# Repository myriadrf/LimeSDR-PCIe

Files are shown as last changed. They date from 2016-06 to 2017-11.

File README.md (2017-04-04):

# LimeSDR-PCIe

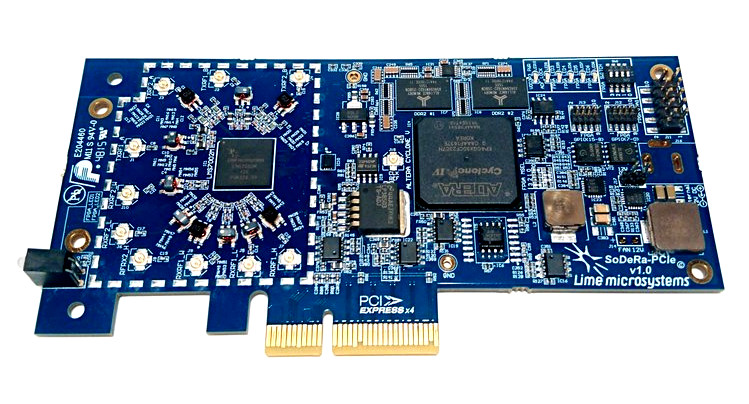
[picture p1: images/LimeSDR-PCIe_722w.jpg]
LimeSDR PCIe board


The [LimeSDR](https://myriadrf.org/projects/limesdr/) board provides a hardware platform for developing and prototyping high-performance and logic-intensive digital and RF designs using Altera’s Cyclone IV FPGA and Lime Microsystems transceiver.

## Contents

The directory structure is as follows:
         
      gateware/                  - Altera Cyclone IV FPGA project

      hardware/<version>/
          DFM/             	- Desgn for Manufacture related files
          EDA/              - Altium project files
          Info/            	- Files like schematic, BOM, 3D models etc. for end user

## Licensing

### Hardware

The hardware designs are licensed under a Creative Commons Attribution 3.0 Unported licence.

### FPGA design

For details of the FPGA design licensing please see the associated COPYING file(s). However, please note that this does not extend to any files provided with the Altera design tools or other third party IP, and see the relevant files for the associated terms and conditions.

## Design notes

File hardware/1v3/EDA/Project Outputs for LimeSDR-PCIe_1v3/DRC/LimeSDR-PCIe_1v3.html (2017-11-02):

Altium

# Design Rule Verification Report

Date: | | 2017-03-17
Time: | | 19:25:50
Elapsed Time: | | 00:03:00
Filename: | | E:\Saniok\Lime Micro\Lime PCBs\LimeSDR-PCIe_1v3\Altium Designer design files\PCB\LimeSDR-PCIe_1v3.PcbDoc

Warnings: | | 0
Rule Violations: | | 0

## Summary

Warnings | Count
Total | 0

Rule Violations | Count
Component Clearance Constraint ( Horizontal Gap = -1mm, Vertical Gap = 0.254mm ) (InComponent('R107') or InComponent('R113') or InComponent('R114') or InComponent('R115') or InComponent('R116') or InComponent('R117') or InComponent('R118')),(InComponent('R107') or InComponent('R113') or InComponent('R114') or InComponent('R115') or InComponent('R116') or InComponent('R117') or InComponent('R118')) | 0
Short-Circuit Constraint (Allowed=Yes) (InComponent('IC8') and IsComponentPad and ((Name='IC8-H14') or (Name='IC8-C10') or (Name='IC8-A11') or (Name='IC8-A12') )),(All) | 0
Width Constraint (Min=0.1mm) (Max=10mm) (Preferred=0.2mm) (All) | 0
Component Clearance Constraint ( Horizontal Gap = -1mm, Vertical Gap = Infinite ) (InComponent('IC9')),(InComponent('IC10')) | 0
Differential Pairs Uncoupled Length using the Gap Constraints (Min=0.1mm) (Max=0.3mm) (Prefered=0.2mm) and Width Constraints (Min=0.1mm) (Max=0.3mm) (Prefered=0.2mm) (InNetClass('RX_RF')) | 0
Differential Pairs Uncoupled Length using the Gap Constraints (Min=0.1mm) (Max=0.3mm) (Prefered=0.2mm) and Width Constraints (Min=0.1mm) (Max=0.3mm) (Prefered=0.2mm) (InNetClass('TX_RF')) | 0
Differential Pairs Uncoupled Length using the Gap Constraints (Min=0.1mm) (Max=0.3mm) (Prefered=0.1mm) and Width Constraints (Min=0.2mm) (Max=0.2mm) (Prefered=0.2mm) (InNetClass('FX3_DATA')) | 0
Matched Lengths(Tolerance=0.5mm) (InNetClass('LMS_PORT2')) | 0
Matched Lengths(Tolerance=0.5mm) (InNetClass('LMS_PORT1')) | 0
Differential Pairs Uncoupled Length using the Gap Constraints (Min=0.1mm) (Max=0.2mm) (Prefered=0.1mm) and Width Constraints (Min=0.1mm) (Max=0.4mm) (Prefered=0.1mm) (InNetClass('DDR2_1_CK') or InNetClass('DDR2_1_CK')) | 0
Modified Polygon (Allow modified: No), (Allow shelved: No) | 0
Height Constraint (Min=0mm) (Max=2.67mm) (Prefered=2.67mm) (OnBottomLayer) | 0
Component Clearance Constraint ( Horizontal Gap = 0.01mm, Vertical Gap = 0.254mm ) (All),(All) | 0
Differential Pairs Uncoupled Length using the Gap Constraints (Min=0.1mm) (Max=0.3mm) (Prefered=0.1mm) and Width Constraints (Min=0.1mm) (Max=0.5mm) (Prefered=0.2mm) (All) | 0
Height Constraint (Min=0mm) (Max=14.47mm) (Prefered=14.47mm) (OnTopLayer) | 0
Hole Size Constraint (Min=0.2mm) (Max=10mm) (All) | 0
Pads and Vias to follow the Drill pairs settings | 0
Routing Via (MinHoleWidth=0.2mm) (MaxHoleWidth=4.5mm) (PreferredHoleWidth=0.2mm) (MinWidth=0.31mm) (MaxWidth=5mm) (PreferedWidth=0.4mm) (All) | 0
Width Constraint (Min=0.1mm) (Max=5mm) (Preferred=0.2mm) (All) | 0
Power Plane Connect Rule(Relief Connect )(Expansion=0.508mm) (Conductor Width=0.254mm) (Air Gap=0.254mm) (Entries=4) (All) | 0
Un-Routed Net Constraint ( (All) ) | 0
Short-Circuit Constraint (Allowed=No) (All),(All) | 0
Clearance Constraint (Gap=0.1mm) (All),(All) | 0
Routing Layers(All) | 0
Hole To Hole Clearance (Gap=0.15mm) (All),(All) | 0
Net Antennae (Tolerance=0mm) (All) | 0
Matched Lengths(Tolerance=0.5mm) (InNetClass('DDR2_2_DQ[0..15]')) | 0
Matched Lengths(Tolerance=0.5mm) (InNetClass('DDR2_2_A[0..12]')) | 0
Matched Lengths(Tolerance=0.5mm) (InNetClass('DDR2_1_DQ[0..15]')) | 0
Matched Lengths(Tolerance=0.5mm) (InNetClass('DDR2_1_A[0..12]')) | 0
Differential Pairs Uncoupled Length using the Gap Constraints (Min=0.1mm) (Max=0.2mm) (Prefered=0.1mm) and Width Constraints (Min=0.1mm) (Max=0.4mm) (Prefered=0.1mm) (InNet('FX3_XTAL_N') or InNet('FX3_XTAL_P')) | 0
Total | 0

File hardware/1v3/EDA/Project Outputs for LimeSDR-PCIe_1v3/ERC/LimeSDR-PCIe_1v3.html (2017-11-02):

Altium

# Electrical Rule Check Report

Date: | | 2017-03-17
Time: | | 19:28:52
Filename: | | E:\Saniok\Lime Micro\Lime PCBs\LimeSDR-PCIe_1v3\Altium Designer design files\Project Outputs for LimeSDR-PCIe_1v3\ERC\LimeSDR-PCIe_1v3.html

Class | Document | Message
Warning | 13_Periphs.SchDoc | FPGA_LED1_R contains IO Pin and Power Pin objects (Pin LED1-3,Pin IC8-E20,Pin LEDS1-K1)
Warning | 13_Periphs.SchDoc | FPGA_LED2_R contains IO Pin and Power Pin objects (Pin LED4-3,Pin IC8-G21,Pin LEDS1-K2)

Warning

16_BoardPowerSupply.SchDoc

GND contains IO Pin and Power Pin objects (Pin J11-2,Pin IC17-5,Pin J11-10,Pin IC12-A3,Pin IC11-A3,Pin IC12-A7,Pin IC11-A7,Pin IC8-A11,Pin IC8-A12,Pin IC12-B2,Pin IC11-B2,Pin IC12-B8,Pin IC11-B8,Pin IC8-B18,Pin IC12-D2,Pin IC11-D2,Pin IC8-D2,Pin IC12-D8,Pin IC11-D8,Pin IC8-D10,Pin IC8-D11,Pin IC8-D12,Pin IC8-D13,Pin IC8-D16,Pin IC12-E3,Pin IC11-E3,Pin IC12-E7,Pin IC11-E7,Pin IC12-F2,Pin IC11-F2,Pin IC12-F8,Pin IC11-F8,Pin IC8-F12,Pin IC8-G18,Pin IC12-H2,Pin IC11-H2,Pin IC12-H8,Pin IC11-H8,Pin IC8-H17,Pin IC12-J3,Pin IC11-J3,Pin IC12-J7,Pin IC11-J7,Pin IC8-J15,Pin LED9-K,Pin LED8-K,Pin LED7-K,Pin LED6-K,Pin LED5-K,Pin IC12-N1,Pin IC11-N1,Pin IC12-P9,Pin IC11-P9)
Warning | 05_LMS7002M_RF1.SchDoc | Net NetC10_1 has no driving source (Pin C10-1,Pin IC4-5)
Warning | 05_LMS7002M_RF1.SchDoc | Net NetC18_1 has no driving source (Pin C18-1,Pin IC5-5)
Warning | 06_LMS7002M_RF2.SchDoc | Net NetC29_1 has no driving source (Pin C29-1,Pin IC6-5)
Warning | 06_LMS7002M_RF2.SchDoc | Net NetC37_1 has no driving source (Pin C37-1,Pin IC7-5)
Warning | 14_Clocks_1.SchDoc | Net NetC325_2 has no driving source (Pin C325-2,Pin XO3-7)
Warning | 16_BoardPowerSupply.SchDoc | Net NetC381_2 has no driving source (Pin C381-2,Pin FR51-2,Pin IC24-5,Pin IC24-8)
Warning | 16_BoardPowerSupply.SchDoc | Net NetC389_2 has no driving source (Pin C389-2,Pin FR52-2,Pin IC26-5,Pin IC26-8)
Warning | 16_BoardPowerSupply.SchDoc | Net NetC403_2 has no driving source (Pin C403-2,Pin FR53-2,Pin IC29-5,Pin IC29-8)
Warning | 16_BoardPowerSupply.SchDoc | Net NetC420_2 has no driving source (Pin C420-2,Pin FR55-2,Pin IC32-3)
Warning | 16_BoardPowerSupply.SchDoc | Net NetC421_2 has no driving source (Pin C421-2,Pin IC32-1,Pin R178-2,Pin R179-1)
Warning | 16_BoardPowerSupply.SchDoc | Net NetIC32_8 has no driving source (Pin IC32-8,Pin R176-2,Pin R177-2)
Warning | 14_Clocks_1.SchDoc | Net NetR118_2 has no driving source (Pin R118-2,Pin XO3-1)
Warning | 11_FPGA_power.SchDoc | VCC2P5A_FPGA contains IO Pin and Power Pin objects (Pin J11-4,Pin IC8-F4,Pin IC8-F19,Pin IC8-L4,Pin IC8-P7,Pin IC8-T5,Pin IC8-U19,Pin IC8-V4)
Warning | 16_BoardPowerSupply.SchDoc | VCC3P3 contains IO Pin and Power Pin objects (Pin IC10-2,Pin IC8-E13,Pin IC8-E14,Pin IC8-E15,Pin IC8-E16,Pin IC8-F14,Pin IC8-G4,Pin IC8-H19,Pin IC8-J18,Pin IC8-K18)

Back to top

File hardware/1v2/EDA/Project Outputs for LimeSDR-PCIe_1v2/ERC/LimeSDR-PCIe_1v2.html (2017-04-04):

Altium

# Electrical Rule Check Report

Date: | | 2016-09-22
Time: | | 11:58:19
Filename: | | E:\Saniok\Lime Micro\Lime PCBs\LimeSDR-PCIe_1v2\Altium Designer Design Files\Project Outputs for LimeSDR-PCIe_1v1\ERC\LimeSDR-PCIe_1v2.html

Class | Document | Message
Warning | 13_Periphs.SchDoc | FPGA_LED1_R contains IO Pin and Power Pin objects (Pin LED1-3,Pin IC8-E20,Pin LEDS1-K1)
Warning | 13_Periphs.SchDoc | FPGA_LED2_R contains IO Pin and Power Pin objects (Pin LED4-3,Pin IC8-G21,Pin LEDS1-K2)

Warning

16_BoardPowerSupply.SchDoc

GND contains IO Pin and Power Pin objects (Pin J11-2,Pin IC18-5,Pin J11-10,Pin IC12-A3,Pin IC11-A3,Pin IC12-A7,Pin IC11-A7,Pin IC8-A11,Pin IC8-A12,Pin IC12-B2,Pin IC11-B2,Pin IC12-B8,Pin IC11-B8,Pin IC8-B18,Pin IC12-D2,Pin IC11-D2,Pin IC8-D2,Pin IC12-D8,Pin IC11-D8,Pin IC8-D10,Pin IC8-D11,Pin IC8-D12,Pin IC8-D13,Pin IC8-D16,Pin IC12-E3,Pin IC11-E3,Pin IC12-E7,Pin IC11-E7,Pin IC12-F2,Pin IC11-F2,Pin IC12-F8,Pin IC11-F8,Pin IC8-F12,Pin IC8-G18,Pin IC12-H2,Pin IC11-H2,Pin IC12-H8,Pin IC11-H8,Pin IC8-H14,Pin IC8-H17,Pin IC12-J3,Pin IC11-J3,Pin IC12-J7,Pin IC11-J7,Pin IC8-J15,Pin LED9-K,Pin LED8-K,Pin LED7-K,Pin LED6-K,Pin LED5-K,Pin IC12-N1,Pin IC11-N1,Pin IC12-P9,Pin IC11-P9)
Warning | 05_LMS7002M_RF1.SchDoc | Net NetC10_1 has no driving source (Pin C10-1,Pin IC4-5)
Warning | 05_LMS7002M_RF1.SchDoc | Net NetC18_1 has no driving source (Pin C18-1,Pin IC5-5)
Warning | 06_LMS7002M_RF2.SchDoc | Net NetC29_1 has no driving source (Pin C29-1,Pin IC6-5)
Warning | 06_LMS7002M_RF2.SchDoc | Net NetC37_1 has no driving source (Pin C37-1,Pin IC7-5)
Warning | 16_BoardPowerSupply.SchDoc | Net NetC379_2 has no driving source (Pin C379-2,Pin FR51-2,Pin IC25-5,Pin IC25-8)
Warning | 16_BoardPowerSupply.SchDoc | Net NetC387_2 has no driving source (Pin C387-2,Pin FR52-2,Pin IC27-5,Pin IC27-8)
Warning | 16_BoardPowerSupply.SchDoc | Net NetC401_2 has no driving source (Pin C401-2,Pin FR53-2,Pin IC30-5,Pin IC30-8)
Warning | 16_BoardPowerSupply.SchDoc | Net NetC418_2 has no driving source (Pin C418-2,Pin FR55-2,Pin IC33-3)
Warning | 16_BoardPowerSupply.SchDoc | Net NetC419_2 has no driving source (Pin C419-2,Pin IC33-1,Pin R176-2,Pin R177-1)
Warning | 16_BoardPowerSupply.SchDoc | Net NetIC33_8 has no driving source (Pin IC33-8,Pin R174-2,Pin R175-2)
Warning | 11_FPGA_power.SchDoc | VCC2P5A_FPGA contains IO Pin and Power Pin objects (Pin J11-4,Pin IC8-F4,Pin IC8-F19,Pin IC8-L4,Pin IC8-N12,Pin IC8-T5,Pin IC8-U19,Pin IC8-V4)
Warning | 16_BoardPowerSupply.SchDoc | VCC3P3 contains IO Pin and Power Pin objects (Pin IC10-2,Pin IC8-E13,Pin IC8-E14,Pin IC8-E15,Pin IC8-E16,Pin IC8-F14,Pin IC8-G4,Pin IC8-H19,Pin IC8-J18,Pin IC8-K18)

Back to top

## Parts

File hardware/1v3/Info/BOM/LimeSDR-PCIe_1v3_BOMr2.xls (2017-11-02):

Item # | Comment | Quantity | Designator | Footprint | Manufacturer | Manufacturer Part Number 1 | Supplier 1 | Supplier Part Number 1 | Part Description | Assembly Info
1 | 10pF, 5% | 4 | C1, C352, C355, C356 | CAP0402 | AVX | 04023A100JAT2A | Farnell | 2332478RL | 10pF ±5% 25V C0G, NP0 Ceramic Capacitor -55°C ~ 125°C Surface Mount, MLCC 0402 (1005 Metric) 0.039" L x 0.020" W (1.00mm x 0.50mm)
2 | 1uF, 10V | 4 | C2, C3, C318, C323 | CAP0402 | TDK | GRM155R61A105KE15J | Newark | 490-6298-2-ND | 1µF ±10% 10V X5R Ceramic Capacitor -55°C ~ 85°C Surface Mount, MLCC 0402 (1005 Metric) 0.039" L x 0.020" W (1.00mm x 0.50mm)
3 | 100nF, 10% | 183 | C4, C5, C7, C8, C23, C24, C26, C27, C101, C102, C103, C104, C105, C106, C107, C108, C109, C110, C111, C112, C113, C114, C115, C116, C117, C118, C119, C126, C132, C138, C144, C150, C156, C162, C168, C169, C170, C171, C172, C173, C174, C175, C176, C177, C178, C179, C180, C181, C182, C183, C184, C185, C186, C187, C188, C189, C190, C191, C192, C193, C194, C195, C196, C197, C198, C199, C200, C201, C202, C203, C204, C205, C206, C207, C208, C209, C210, C211, C212, C213, C214, C215, C216, C217, C218, C219, C220, C221, C222, C223, C224, C225, C226, C227, C228, C229, C230, C231, C232, C233, C234, C235, C236, C237, C238, C239, C240, C241, C242, C243, C244, C245, C246, C247, C248, C249, C250, C251, C252, C253, C254, C256, C257, C258, C259, C260, C261, C262, C263, C265, C266, C267, C268, C273, C274, C276, C277, C278, C279, C281, C282, C283, C284, C286, C287, C288, C289, C290, C291, C292, C293, C298, C299, C300, C302, C303, C304, C305, C306, C312, C313, C314, C327, C335, C338, C339, C345, C353, C354, C357, C358, C359, C361, C363, C365, C367, C378, C397, C398, MN5, MN8, MN33, MN36 | CAP0402 | Murata Electronics | GRM155R71C104KA88D | Mouser | 81-GRM155R71C104KA88 | 0.10µF ±10% 16V X7R Ceramic Capacitor -55°C ~ 125°C Surface Mount, MLCC 0402 (1005 Metric) 0.039" L x 0.020" W (1.00mm x 0.50mm)
4 | 100nF, 16V | 6 | C6, C25, C317, C320, C324, C331 | CAP0402 | Murata Electronics | GRM155R71C104KA88D | Mouser | 81-GRM155R71C104KA88 | 0.10µF ±10% 16V X7R Ceramic Capacitor -55°C ~ 125°C Surface Mount, MLCC 0402 (1005 Metric) 0.039" L x 0.020" W (1.00mm x 0.50mm)
5 | 100pF, 50V | 20 | C9, C10, C13, C15, C16, C17, C18, C19, C28, C29, C32, C34, C35, C36, C37, C38, C321, C322, C332, C333 | CAP0402 | Yageo | CC0402JRNPO9BN101 | Digi-Key | 311-1024-1-ND | 100pF ±5% 50V C0G, NP0 Ceramic Capacitor -55°C ~ 125°C Surface Mount, MLCC 0402 (1005 Metric) 0.039" L x 0.020" W (1.00mm x 0.50mm)
6 | 47pF | 10 | C11, C12, C20, C21, C30, C31, C39, C40, C315, C316 | CAP0402 | TDK Corporation | C1005C0G1H470F050BA | Digi-Key | 445-5361-1-ND | 47pF ±1% 50V C0G, NP0 Ceramic Capacitor -55°C ~ 125°C Surface Mount, MLCC 0402 (1005 Metric) 0.039" L x 0.020" W (1.00mm x 0.50mm) | NF(C315 C316)
7 | 470pF, 50V | 4 | C14, C22, C33, C41 | CAP0402 | TDK Corporation | C1005C0G1H471J050BA | Digi-Key | 445-2656-6-ND | 470pF ±5% 50V C0G, NP0 Ceramic Capacitor -55°C ~ 125°C Surface Mount, MLCC 0402 (1005 Metric) 0.039" L x 0.020" W (1.00mm x 0.50mm)
8 | 1uF, 20% | 50 | C42, C44, C46, C48, C50, C52, C53, C54, C55, C56, C57, C58, C59, C60, C61, C62, C63, C64, C66, C68, C70, C72, C73, C74, C75, C76, C77, C78, C79, C80, C81, C82, C83, C84, C85, C86, C87, C88, C89, C90, C91, C92, C93, C94, C95, C96, C97, C98, C99, C100 | CAP0201 | TDK Corporation | C0603X5R0J105M030BC | Digi-Key | 445-8008-1-ND | 1µF ±20% 6.3V X5R Ceramic Capacitor -55°C ~ 85°C Surface Mount, MLCC 0201 (0603 Metric) 0.024" L x 0.012" W (0.60mm x 0.30mm)
9 | 1nF, 10% | 9 | C43, C45, C47, C49, C51, C65, C67, C69, C71 | CAP0201 | TDK Corporation | C0603X7R1E102K030BA | Digi-Key | 445-7275-1-ND | 1000pF ±10% 25V X7R Ceramic Capacitor -55°C ~ 125°C Surface Mount, MLCC 0201 (0603 Metric) 0.024" L x 0.012" W (0.60mm x 0.30mm)
10 | 220uF, 4V | 14 | C120, C121, C122, C127, C128, C133, C134, C139, C145, C151, C275, C405, C406, C407 | CAP1206 | Murata Electronics North America | GRM31CR60G227ME11L | Digi-Key | 490-9774-1-ND | 220µF ±20% 4V X5R Ceramic Capacitor -55°C ~ 85°C Surface Mount, MLCC 1206 (3216 Metric) 0.126" L x 0.063" W (3.20mm x 1.60mm) | NF(C407)
11 | 10uF, 6.3V | 13 | C123, C129, C135, C141, C147, C153, C159, C165, C270, C295, C386, C395, C396 | CAP0603 | Yageo | CC0603MRX5R5BB106 | Digi-Key | 311-1448-2-ND | 10µF ±20% 6.3V X5R Ceramic Capacitor -55°C ~ 85°C Surface Mount, MLCC 0603 (1608 Metric) 0.063" L x 0.031" W (1.60mm x 0.80mm)
12 | 4.7uF, 6.3V | 35 | C124, C130, C136, C142, C148, C154, C160, C166, C271, C296, C319, C326, C330, C334, C360, C362, C364, C366, C375, C376, C380, C381, C382, C388, C389, C390, C393, C400, C401, C402, C403, C404, C412, C415, C416 | CAP0402 | Murata Electronics North America | GRM155R60J475ME87D | Digi-Key | 490-5408-1-ND | 4.7µF ±20% 6.3V X5R Ceramic Capacitor -55°C ~ 85°C Surface Mount, MLCC 0402 (1005 Metric) 0.039" L x 0.020" W (1.00mm x 0.50mm) | NF(C334)
13 | 1uF, 10% | 12 | C125, C131, C137, C143, C149, C155, C161, C167, C272, C297, C387, C408 | CAP0402 | TDK | GRM155R61A105KE15J | Newark | 490-6298-2-ND | 1µF ±10% 10V X5R Ceramic Capacitor -55°C ~ 85°C Surface Mount, MLCC 0402 (1005 Metric) 0.039" L x 0.020" W (1.00mm x 0.50mm)
14 | 100uF, 6.3V | 10 | C140, C146, C152, C157, C158, C163, C164, C383, C384, C385 | CAP1206 | MURATA | GRM31CR60J107ME39L. | Farnell | 1735535 | SMD Multilayer Ceramic Capacitor, GRM Series, 100 µF, ± 20%, X5R, 6.3 V, 1206 [3216 Metric] | NF(C385)
15 | 0.1uF | 6 | C255, C264, C269, C280, C285, C294 | CKCA43X7R1C104M100AA | TDK | CKCA43X7R1C104M100AA | Mouser | 810-CKCA43X7R1C104M | CAP ARRAY 0.1UF 16V X7R 1206
16 | 22nF, 50V | 11 | C301, C307, C308, C309, C310, C311, C373, C374, C377, C394, C411 | CAP0402 | Kemet | C0402C223K5RACTU | Digi-Key | 399-7780-1-ND | 0.022µF ±10% 50V X7R Ceramic Capacitor -55°C ~ 125°C Surface Mount, MLCC 0402 (1005 Metric) 0.039" L x 0.020" W (1.00mm x 0.50mm)
17 | 18nF, 16V | 1 | C325 | CAP0402 | Yageo | CC0402KRX7R7BB183 | Digi-Key | 311-1706-1-ND | CAP CER 0.018UF 16V X7R 0402
18 | 100pF, 5% | 13 | C328, C329, C336, C337, C340, C341, C342, C343, C344, MN25, MN28, MN53, MN56 | CAP0402 | Yageo | CC0402JRNPO9BN101 | Digi-Key | 311-1024-1-ND | 100pF ±5% 50V C0G, NP0 Ceramic Capacitor -55°C ~ 125°C Surface Mount, MLCC 0402 (1005 Metric) 0.039" L x 0.020" W (1.00mm x 0.50mm)
19 | 1nF, 10% | 2 | C346, C347 | CAP0402 | Murata Electronics | GCM155R71H102KA37D | Mouser | 81-GCM155R71H102KA7D | 1000pF ±10% 50V X7R Ceramic Capacitor -55°C ~ 125°C Surface Mount, MLCC 0402 (1005 Metric) 0.039" L x 0.020" W (1.00mm x 0.50mm)
20 | 22pF, 5% | 3 | C348, C349, C350 | CAP0402 | Yageo | CC0402JRNPO9BN220 | Digi-Key | 311-1018-2-ND | 22pF ±5% 50V C0G, NP0 Ceramic Capacitor -55°C ~ 125°C Surface Mount, MLCC 0402 (1005 Metric) 0.039" L x 0.020" W (1.00mm x 0.50mm)
21 | 220pF, 10% | 1 | C351 | CAP0402 | Yageo | CC0402KRX7R9BB221 | Digi-Key | 311-1035-2-ND | 220pF ±10% 50V X7R Ceramic Capacitor -55°C ~ 125°C Surface Mount, MLCC 0402 (1005 Metric) 0.039" L x 0.020" W (1.00mm x 0.50mm)
22 | 10uF, 25V | 10 | C368, C369, C370, C371, C372, C379, C399, C419, C420, C421 | CAP0603 | Murata Electronics North America | GRM188R61E106MA73D | Digi-Key | 490-7202-2-ND | 10µF ±20% 25V X5R Ceramic Capacitor -55°C ~ 85°C Surface Mount, MLCC 0603 (1608 Metric) 0.063" L x 0.031" W (1.60mm x 0.80mm)
23 | 4.7pF | 1 | C391 | CAP0402 | MURATA | GRM1555C1H4R7CA01D | Farnell | 2434644 | 4.7pF ±0.25pF 50V C0G, NP0 Ceramic Capacitor -55°C ~ 125°C Surface Mount, MLCC 0402 (1005 Metric) 0.039" L x 0.020" W (1.00mm x 0.50mm)
24 | 1200pF | 1 | C392 | CAP0402 | Kemet | C0402C122J5GACTU | Digi-Key | 399-7334-1-ND | 1200pF ±5% 50V C0G, NP0 Ceramic Capacitor -55°C ~ 125°C Surface Mount, MLCC 0402 (1005 Metric) 0.039" L x 0.020" W (1.00mm x 0.50mm)
25 | 68pF | 1 | C409 | CAP0402 | Kemet | CBR04C680F3GAC | Digi-Key | 399-11255-1-ND | 68pF ±1% 25V C0G, NP0 Ceramic Capacitor -55°C ~ 125°C Surface Mount, MLCC 0402 (1005 Metric) 0.039" L x 0.020" W (1.00mm x 0.50mm)
26 | 1500pF | 1 | C410 | CAP0402 | Samsung Electro-Mechanics America, Inc. | CL05B152KB5NNNC | Digi-Key | 1276-1521-1-ND | 1500pF ±10% 50V X7R Ceramic Capacitor -55°C ~ 125°C Surface Mount, MLCC 0402 (1005 Metric) 0.039" L x 0.020" W (1.00mm x 0.50mm)
27 | 10uF, 20% | 4 | C413, C414, C417, C418 | CAP0603 | Yageo | GRM188R61C106MA73D | Digi-Key | 490-7201-2-ND | 10µF ±20% 16V X5R Ceramic Capacitor -55°C ~ 85°C Surface Mount, MLCC 0603 (1608 Metric) 0.063" L x 0.031" W (1.60mm x 0.80mm)
28 | Fiducial | 8 | F1, F2, F3, F4, F5, F6, F7, F8 | Fiducial | - | - | - | - | -
29 | Local 'Fiducial | 8 | FL1, FL2 | Fiducial_local | - | - | - | - | -
30 | 600R, 0.27A | 38 | FR1, FR2, FR3, FR4, FR5, FR6, FR7, FR8, FR9, FR10, FR11, FR12, FR13, FR14, FR15, FR16, FR17, FR18, FR19, FR20, FR21, FR22, FR23, FR24, FR25, FR26, FR27, FR28, FR29, FR30, FR31, FR32, FR33, FR34, FR35, FR47, FR48, FR49 | RES0201 | Taiyo Yuden | BK0603TS601-T | Digi-Key | 587-3277-1-ND | FERRITE BEAD 600 OHM 0201 1LN | NF(FR29 FR31)
31 | 600R, 2A | 18 | FR36, FR37, FR38, FR39, FR40, FR41, FR42, FR43, FR44, FR45, FR46, FR50, FR51, FR52, FR53, FR54, FR55, FR56 | RES0805 | TDK Corporation | MPZ2012S601AT000 | Digi-Key | 445-2206-2-ND | FERRITE BEAD 600 OHM 0805 1LN
32 | LMS7002M | 1 | IC1 | LMS7002M_v2 | Lime Microsystems | LMS7002M | Lime Microsystems | LMS7002M | IC FPRF Transceiver LMS7002M; 261 pin aQFN
33 | M24128 | 2 | IC2, IC15 | 24FC512 | STMicroelectronics | M24128-DRDW8TP/K | Digi-Key | 497-15336-1-ND | IC EEPROM 128KBIT 1MHZ 8TSSOP
34 | 24FC512 | 1 | IC3 | 24FC512 | Microchip Technology | 24FC512-I/ST | Digi-Key | 24FC512-I/ST-ND | IC EEPROM 512KBIT 1MHZ 8TSSOP
35 | SKY13323 | 4 | IC4, IC5, IC6, IC7 | SKY13323-378LF | Skyworks Solutions Inc. | SKY13323-378LF | Digi-Key | 683-1334-1-ND | IC SPDT 100MHZ-3GHZ 6-MLPD
36 | EP4CGX30CF23C7N | 1 | IC8 | ALTR-FBGA484_A-200 | Altera | EP4CGX30CF23C7N | Digi-Key | 544-2730-ND | IC FPGA 290 I/O 484FBGA
37 | S25FL164K | 1 | IC9 | S25FL164K_WSO8N | Cypress Semiconductor Corp | S25FL164K0XMFI011 | Digi-Key | 1274-1097-ND | IC FLASH 64MBIT 8SO
38 | S25FL164K | 1 | IC10 | SOIC16_WIDE | Cypress Semiconductor Corp | S25FL164K0XMFI003 | Digi-Key | 1274-1109-1-ND | IC FLASH 64MBIT 108MHZ 16SOIC | NF(IC10)
39 | AS4C64M16D2-25BCN | 2 | IC11, IC12 | AS4C64M16D2 | Alliance Memory, Inc. | AS4C64M16D2-25BCN | Digi-Key | 1450-1158-ND | IC SDRAM 64MX16 1.8V 84-FBGA
40 | LE25U40CMDTWG | 1 | IC13 | M25P40-VMN6TPB_SO8N | ON Semiconductor | LE25U40CMDTWG | Digi-Key | LE25U40CMDTWGOSCT-ND | IC FLASH 4MBIT 40MHZ 8SOIC
41 | LM75 | 1 | IC14 | HWSON8_LM75 | NXP Semiconductors | LM75BTP,147 | Digi-Key | 568-9815-2-ND | SENSOR TEMPERATURE I2C 8HWSON
42 | LMK00105 | 1 | IC16 | LMK00105SQ | Texas Instruments | LMK00105SQ/NOPB | Digi-Key | LMK00105SQ/NOPBCT-ND | IC CLK BUFFER 2:5 200MHZ 24WQFN
43 | AD5601BKSZ-REEL7 | 1 | IC17 | AD5601_SOT23-6 | Analog Devices | AD5601BKSZ-REEL7 | Digi-Key | AD5601BKSZ-REEL7TR-ND | IC DAC 8BIT BUFF V-OUT SC70-6
44 | ADF4002 | 1 | IC18 | ADF4002 | Analog Devices Inc | ADF4002BCPZ-RL7 | Digi-Key | ADF4002BCPZ-RL7CT-ND | IC PLL FREQUENCY SYNTH 20-LFCSP
45 | Si5351C | 1 | IC19 | Si5351C_20QFN | Silicon Labs | SI5351C-B-GM | Digi-Key | 336-2402-5-ND | IC CLK GENERATOR 200MHZ 20QFN
46 | AP7361-FGE | 6 | IC20, IC24, IC26, IC28, IC29, IC31 | AP7361 | Diodes Incorporated | AP7361-FGE-7 | Digi-Key | AP7361-FGE-7DICT-ND | IC REG LDO ADJ 1A 8DFN
47 | LTC4357 | 2 | IC21, IC22 | LTC4357 | Linear Technology | LTC4357IDCB#TRMPBF | Digi-Key | LTC4357IDCB#TRMPBFDKR-ND | IC OR CTRLR N+1 6DFN | NF(IC21 IC22)
48 | ADP2386 | 2 | IC23, IC27 | ADP2386 | Analog Devices Inc. | ADP2386ACPZN-R7 | Digi-Key | ADP2386ACPZN-R7DKR-ND | IC REG BUCK ADJ 6A SYNC 24LFCSP
49 | RT9026 | 1 | IC25 | MSOP10 | Richtek USA Inc. | RT9026GFP | Digi-Key | 1028-1010-1-ND | IC DDR TERMINATION REG 10MSOP
50 | LP38503TS | 1 | IC30 | TO-263-5_v2 | Texas Instruments | LP38503TS-ADJ/NOPB | Digi-Key | LP38503TS-ADJ/NOPB-ND | IC REG LDO ADJ 3A TO263-5
51 | SPX3819R2 | 1 | IC32 | SPX3819R2-L/TR | Exar Corporation | SPX3819R2-L/TR | Digi-Key | 1016-1588-1-ND | Linear Voltage Regulator IC Positive Adjustable 1 Output Adjustable 500mA 8-DFN (2x3)
52 | U.FL/MMCX | 12 | J1, J2, J3, J4, J5, J6, J7, J8, J9, J10, J15, J16 | MMCX_UFL_conn_u | Molex, LLC | 0734120110 | Digi-Key | WM5587CT-ND | CONN UMC RCPT STR 50 OHM SMD
53 | JTAG_10pinConnector | 1 | J11 | HEADER5x2_SM | MOLEX | 54202-G0805LF | Digi-Key | 609-4723-ND | 10 Positions Header, Unshrouded Connector 0.100" (2.54mm) Surface Mount Gold or Gold, GXT
54 | FPGA GPIO | 2 | J12, J13 | SWD_10_pin | Harwin Inc | M50-3600542 | Digi-Key | 952-1389-ND | CONN HDR 1.27MM SMD AU 10POS
55 | 12V FAN | 1 | J14 | HDR_1x2 | 3M | 961102-6404-AR | Digi-Key | 3M9447-ND | 2 Positions Header, Unshrouded Connector 0.100" (2.54mm) Through Hole Gold
56 | CONN_PWR_JACK_2.1x5.5mm | 1 | J17 | CONN_PWR_JACK_v2 | SWITCHCRAFT | RAPC712X | Farnell | 1608726 | Gender Jack, Current Rating 5A, Pin Diameter 2.5mm, Connector Mounting Through Hole Mount, Contact Termination Type Solder, Barrel O.D. 6.3mm | NF(J17)
57 | 12V | 1 | J18 | HDR_1x2 | 3M | 961102-6404-AR | Digi-Key | 3M9447-ND | 2 Positions Header, Unshrouded Connector 0.100" (2.54mm) Through Hole Gold
58 | 2.2uH | 1 | L1 | FDVE1040_TOKO_INDUCTOR | Vishay Dale | IHLP4040DZER2R2M01 | Digi-Key | 541-1299-1-ND | FIXED IND 2.2UH 12A 9 MOHM SMD
59 | 1uH | 1 | L2 | FDVE1040_TOKO_INDUCTOR | Vishay Dale | IHLP3232DZER1R0M01 | Digi-Key | 541-1371-6-ND | FIXED IND 1UH 18A 5.78 MOHM SMD
60 | LED_RG_SMD | 2 | LED1, LED4 | LED-2x0603 | Avago Technologies US Inc. | HSMF-C165 | Digi-Key | 516-1419-1-ND | LED GREEN/RED DIFFUSED 0603 SMD | NF(LED1 LED4)
61 | LED_RG | 2 | LED2, LED3 |  | Visual Communications Company - VCC | 4301F1/5 | Digi-Key | 4301F1/5-ND | LED GRN/RED DIFF 3MM ROUND T/H
62 | LED_green | 5 | LED5, LED6, LED7, LED8, LED9 | LED-0603-GREEN | Broadcom Limited | HSMG-C190 | Digi-Key | 516-1425-2-ND | LED GREEN DIFFUSED 0603 SMD
63 | 2xLED standoff | 1 | LEDS1 | LED_STANDOFF_H-201C | Bivar Inc. | H-201C | Digi-Key | 492-1790-ND | LED HOLDER RA 3MM 2LD NYL BK
64 | RFI Shield clip | 10 | MECH1, MECH2, MECH3, MECH4, MECH5, MECH6, MECH7, MECH8, MECH9, MECH10 | RFI_SHIELD_CLPS_MINI | HARWIN | S0971-46R | Farnell | 2361677 | RFI SHIELD CLIP MINI TIN SMD | NF(MECH1 MECH2 MECH3 MECH4 MECH5 MECH6 MECH7 MECH8 MECH9 MECH10)
65 | # pcs. | 4 | MECH11, MECH12, MECH13, MECH14 | PCB_standoff | Keystone Electronics | 24313 | Digi-Key | 24313K-ND | HEX STANDOFF M3 BRASS 10MM | NF(MECH11 MECH12 MECH13 MECH14)
66 | 100uH | 4 | MN1, MN2, MN29, MN30 | RES0805 | TDK Corporation | MLF2012C101KT000 | Digi-Key | 445-1071-1-ND | FIXED IND 100UH 2MA 3.1 OHM SMD
67 | 47nH | 4 | MN3, MN4, MN31, MN32 | RES0402 | COILCRAFT | 0402HP-47NXJLU | Farnell | 2285856 | Surface Mount High Frequency Inductor, 0402HP Series, 47 nH, ± 5%, 0402 [1005 Metric], 2.4 GHz
68 | 0.5pF | 6 | MN6, MN15, MN22, MN34, MN43, MN50 | CAP0402 | Yageo | CC0402CRNPO9BNR50 | Digi-Key | 311-1001-1-ND | 0.50pF ±0.25pF 50V C0G, NP0 Ceramic Capacitor -55°C ~ 125°C Surface Mount, MLCC 0402 (1005 Metric) 0.039" L x 0.020" W (1.00mm x 0.50mm) | NF(MN6 MN22 MN34 MN50)
69 | 2pF | 6 | MN7, MN21, MN24, MN35, MN49, MN52 | CAP0402 | AVX | 04025U2R0BAT2A | Farnell | 2332536 | SMD Multilayer Ceramic Capacitor, U Series, 2 pF, ± 0.1pF, C0G / NP0, 50 V, 0402 [1005 Metric]
70 | 0uH (0R) | 4 | MN9, MN10, MN37, MN38 | RES0805 | BOURNS | CR0805-J/-000ELF | Farnell | 2008388 | Surface Mount Chip Resistor, Thick Film, CR Series, 0 ohm, 125 mW, ± 5%, 150 V, 0805 [2012 Metric]
71 | 8.2nH, 5% | 6 | MN11, MN12, MN18, MN39, MN40, MN46 | RES0402 | COILCRAFT | 0402HP-8N2XJLU | Farnell | 2285826 | Surface Mount High Frequency Inductor, 0402HP Series, 8.2 nH, ± 5%, 0402 [1005 Metric], 5.4 GHz
72 | 0.8pF | 6 | MN13, MN16, MN27, MN41, MN44, MN55 | CAP0402 | Murata Electronics North America | GRM1555C1HR80BA01D | Digi-Key | 490-6269-1-ND | 0.80pF ±0.1pF 50V C0G, NP0 Ceramic Capacitor -55°C ~ 125°C Surface Mount, MLCC 0402 (1005 Metric) 0.039" L x 0.020" W (1.00mm x 0.50mm)
73 | 1pF | 4 | MN14, MN23, MN42, MN51 | CAP0402 | TDK Corporation | C1005C0G1H010B050BA | Digi-Key | 445-4854-6-ND | 1pF ±0.1pF 50V C0G, NP0 Ceramic Capacitor -55°C ~ 125°C Surface Mount, MLCC 0402 (1005 Metric) 0.039" L x 0.020" W (1.00mm x 0.50mm) | NF(MN14 MN42)
74 | 510pF | 4 | MN17, MN20, MN45, MN48 | CAP0402 | Murata Electronics North America | GRM1555C1H511JA01D | Digi-Key | 490-3237-1-ND | 510pF ±5% 50V C0G, NP0 Ceramic Capacitor -55°C ~ 125°C Surface Mount, MLCC 0402 (1005 Metric) 0.039" L x 0.020" W (1.00mm x 0.50mm)
75 | 1.2pF | 2 | MN19, MN47 | CAP0402 | Murata Electronics North America | GRM1555C1H1R2CA01D | Digi-Key | 490-5927-1-ND | 1.2pF ±0.25pF 50V C0G, NP0 Ceramic Capacitor -55°C ~ 125°C Surface Mount, MLCC 0402 (1005 Metric) 0.039" L x 0.020" W (1.00mm x 0.50mm)
76 | 10nH, 5% | 2 | MN26, MN54 | RES0402 | COILCRAFT | 0402HP-10NXJLU | Farnell | 2285830 | Surface Mount High Frequency Inductor, 0402HP Series, 10 nH, ± 5%, 0402 [1005 Metric], 4.7 GHz
77 | 10k, 1% | 27 | R1, R2, R3, R4, R5, R10, R11, R56, R57, R63, R64, R66, R85, R86, R87, R88, R105, R131, R132, R149, R154, R156, R163, R168, R172, R174, R178 | RES0402 | Yageo | RC0402FR-0710KL | Digi-Key | 311-10.0KLRTR-ND | RES SMD 10K OHM 1% 1/16W 0402
78 | 49.9R, 1% | 20 | R6, R7, R8, R9, R40, R41, R42, R43, R44, R45, R111, R123, R130, R135, R136, R137, RA2, RA3, RA5, RA6 | RES0402 | Samsung Electro-Mechanics America, Inc. | RC1005F49R9CS | Digi-Key | 1276-3469-6-ND | RES SMD 49.9 OHM 1% 1/16W 0402
79 | 2k2, 1% | 2 | R12, R13 | RES0402 | Stackpole Electronics Inc | RMCF0402FT2K20 | Digi-Key | RMCF0402FT2K20CT-ND | RES SMD 2.2K OHM 1% 1/16W 0402
80 | 1k, 1% | 12 | R14, R17, R62, R103, R104, R125, R143, R147, R158, R161, R167, R173 | RES0402 | Stackpole Electronics Inc | RMCF0402FT1K00 | Digi-Key | RMCF0402FT1K00TR-ND | RES SMD 1K OHM 1% 1/16W 0402 | NF(R14 R17)
81 | 100R, 1% | 12 | R15, R16, R18, R19, R73, R76, R77, R79, R82, R83, R89, R90 | RES0402 | Stackpole Electronics Inc. | RMCF0402FT100R | Digi-Key | RMCF0402FT100RDKR-ND | RES SMD 100 OHM 1% 1/16W 0402
82 | 0R | 7 | R20, R33, R34, R35, R37, R38, R39 | RES0201 | Rohm Semiconductor | MCR006YRTJ000 | Digi-Key | RHM0.0CCCT-ND | RES SMD 0.0OHM JUMPER 1/20W 0201
83 | 0R | 52 | R21, R22, R23, R24, R25, R28, R29, R30, R31, R46, R47, R48, R49, R50, R51, R52, R53, R54, R55, R58, R59, R60, R61, R98, R99, R100, R101, R102, R106, R108, R110, R113, R115, R117, R118, R120, R121, R122, R126, R128, R129, R133, R138, R141, R142, R146, R155, R159, R160, R170, R171, R179 | RES0402 | Yageo | RC0402JR-070RL | Digi-Key | 311-0.0JRTR-ND | RES SMD 0.0OHM JUMPER 1/16W 0402 | NF(R52 R55 R59 R60 R98 R99 R100 R117 R120 R122 R126 R133 R138 R179)
84 | 10R | 4 | R26, R27, R32, R36 | RES0201 | Panasonic Electronic Components | ERJ-1GEF10R0C | Digi-Key | P10.0ABCT-ND | RES SMD 10 OHM 1% 1/20W 0201
85 | 22R | 2 | R65, R119 | RES0402 | Yageo | RC0402FR-0722RL | Digi-Key | 311-22.0LRTR-ND | RES SMD 22 OHM 1% 1/16W 0402
86 | 100K | 2 | R67, R84 | RES0402 | Panasonic Electronic Components | ERJ-2GEJ104X | Digi-Key | P100KJCT-ND | RES SMD 100K OHM 5% 1/10W 0402
87 | 4K7 | 6 | R68, R69, R70, R91, R92, R93 | RES0402 | Stackpole Electronics Inc. | RMCF0402JT4K70 | Digi-Key | RMCF0402JT4K70TR-ND | RES SMD 4.7K OHM 5% 1/16W 0402
88 | 2k, 1% | 1 | R71 | RES0402 | Yageo | RC0402FR-072KL | Digi-Key | 311-2KLRCT-ND | RES SMD 2K OHM 1% 1/16W 0402
89 | 8x56R | 6 | R72, R74, R75, R78, R80, R81 | EXB2HV | PANASONIC ELECTRONIC COMPONENTS | EXB2HV560JV | Farnell | 2060070 | RESISTOR,CVEX ARRAY,0402X8, 56R 5%
90 | 249R, 1% | 4 | R94, R95, R96, R97 | RES0402 | Stackpole Electronics Inc | RMCF0402FT249R | Digi-Key | RMCF0402FT249RCT-ND | RMCF0402FT249RCT-ND
91 | 0R | 5 | R107, R109, R112, R114, R116 | RES0402_v2 | Yageo | RC0402JR-070RL | Digi-Key | 311-0.0JRTR-ND | RES SMD 0.0OHM JUMPER 1/16W 0402 | NF(R109 R112 R114 R116)
92 | 10R, 5% | 1 | R124 | RES0402 | Yageo | RC0402JR-0710RL | Digi-Key | 311-10JRTR-ND | RES SMD 10 OHM 5% 1/16W 0402
93 | 470R, 0.5% | 3 | R127, R144, R145 | RES0402 | Panasonic Electronic Components | ERA-2AED471X | Digi-Key | P470DETR-ND | RES SMD 470 OHM 0.5% 1/16W 0402
94 | 330R, 5% | 1 | R134 | RES0402 | Yageo | RC0402JR-07330RL | Digi-Key | 311-330JRTR-ND | RES SMD 330 OHM 5% 1/16W 0402
95 | 0R | 2 | R139, R140 | RES0805 | Vishay Dale | CRCW08050000Z0EA | Digi-Key | 541-0.0ATR-ND | RES SMD 0.0 OHM JUMPER 1/8W 0805
96 | 806R, 1% | 3 | R148, R166, R175 | RES0402 | Stackpole Electronics Inc | RMCF0402FT806R | Digi-Key | RMCF0402FT806RCT-ND | RMCF0402FT806RCT-ND
97 | 44.2k, 1% | 3 | R150, R153, R164 | RES0402 | Panasonic Electronic Components | ERJ-2RKF4422X | Digi-Key | P44.2KLCT-ND | RES SMD 44.2K OHM 1% 1/10W 0402 | NF(R150 R164)
98 | 100k, 5% | 1 | R151 | RES0402 | Panasonic Electronic Components | ERJ-2GEJ104X | Digi-Key | P100KJTR-ND | RES SMD 100K OHM 5% 1/10W 0402
99 | 2.21k, 1% | 1 | R152 | RES0402 | Stackpole Electronics Inc. | RMCF0402FT2K21 | Digi-Key | RMCF0402FT2K21CT-ND | RES SMD 2.21K OHM 1% 1/16W 0402
100 | 750R, 1% | 1 | R157 | RES0402 | Yageo | RC0402FR-07750RL | Digi-Key | 311-750LRCT-ND | RES SMD 750 OHM 1% 1/16W 0402
101 | 560R, 1% | 1 | R162 | RES0402 | Vishay Dale | CRCW0402560RFKED | Digi-Key | 541-560LCT-ND | RES SMD 560 OHM 1% 1/16W 0402
102 | 124k, 1% | 1 | R165 | RES0402 | Panasonic Electronic Components | ERJ-2RKF1243X | Digi-Key | P124KLCT-ND | RES SMD 124K OHM 1% 1/10W 0402
103 | 66.5k, 1% | 1 | R169 | RES0402 | Panasonic Electronic Components | ERJ-2RKF6652X | Digi-Key | P66.5KLDKR-ND | RES SMD 66.5K OHM 1% 1/10W 0402
104 | 39k, 1% | 1 | R176 | RES0402 | Yageo | RC0402FR-0739KL | Digi-Key | 311-39.0KLRCT-ND | RES SMD 39K OHM 1% 1/16W 0402
105 | 23.2k, 1% | 1 | R177 | RES0402 | Yageo | RC0402FR-0723K2L | Digi-Key | YAG3066CT-ND | RES SMD 23.2K OHM 1% 1/16W 0402
106 | 453R, 1% | 2 | RA1, RA4 | RES0402 | Yageo | RC0402FR-07453RL | Digi-Key | YAG3165CT-ND | RES SMD 453 OHM 1% 1/16W 0402
107 | 4 bit switch | 1 | SW1 | SW_4WAY_SMD_1P27 | Omron Electronics Inc-EMC Div | A6H-4101 | Digi-Key | SW1080-ND | SWITCH DIP 4POLES STD SMD 24V
108 | TC1-1-13MA+ | 6 | T1, T3, T5, T6, T8, T10 | TC1-1-13MA+_v2 | Mini-Circuits | TC1-1-13MA+ | Minicircuits | TC1-1-13MA+ | RF balun, TC1-1-13MA+
109 | TCM1-63AX+ | 4 | T2, T4, T7, T9 | TCM1-63AX+_v2 | Mini-circuits | TCM1-63AX+ | Minicircuits | TCM1-63AX+ | RF balun, TCM1-63AX+
110 | TESTPOINT_THT_MINI | 2 | TP1, TP2 | TP-THT-MIDI | Keystone Electronics | 5011 | Digi-Key | 5011K-ND | TEST POINT PC MULTI PURPOSE BLK
111 | MMBD1205 | 1 | VD1 | SOT23-3_v2 | FAIRCHILD SEMICONDUCTOR | MMBD1205 | Digi-Key | MMBD1205CT-ND | DIODE ARRAY GP 100V 200MA SOT23 | NF(VD1)
112 | RF MOSFET | 4 | VT1, VT2, VT3, VT4 | BF1105R_SOT143R4 | NXP Semiconductors | BF1105R,215 | Digi-Key | 568-12530-6-ND | RF MOSFET Transistors Trans MOSFET N-CH 7V 0.03A 4pin(3+Tab)
113 | NDS331N | 1 | VT5 | SOT23-3 | FAIRCHILD SEMICONDUCTOR | NDS331N | Digi-Key | NDS331NCT-ND | MOSFET N-CH 20V 1.3A SSOT3
114 | BSC093N04LS G | 2 | VT6, VT7 | BSC093N04LS_G | Infineon Technologies | BSC093N04LS G | Digi-Key | BSC093N04LS GDKR-ND | MOSFET N-CH 40V 49A TDSON-8 | NF(VT6 VT7)
115 | 30.72 MHz | 1 | XO1 | RAKON_RPT7050A | Rakon | E6245LF | Rakon | E6245LF | TCXO 30.72MHz, E6245LF | NF(XO1)
116 | TCXO 30.72MHz | 1 | XO2 | RAKON_TXCO | Rakon | E5280LF | Rakon | E5280LF | TCXO 30.72MHz, E5280LF
117 | RTX5032A, 40MHz, w VC, w Filter | 1 | XO3 | RAKON_RTX5032A | Rakon | RTX5032A | RAKON | RTX5032A | RTX5032A 40MHz, High performance TCXO, With VC, Filter Enabled, 10-pin 5mm x 3.2 mm x 1.65 mm package | NF(XO3)
118 | CRYSTAL 100MHz | 1 | XO4 | CRYSTAL_4-LCC_v4 | AVX Corp/Kyocera Corp | KC5032A100.000C1GE00 | Digi-Key | 1253-1302-1-ND | OSC XO 100.000MHZ CMOS SMD
119 | CRYSTAL 50MHz (nr. 1) | 1 | XO5 | CRYSTAL_4-LCC_v4 | AVX Corp/Kyocera Corp | KC5032A50.0000CMGE00 | Digi-Key | 1253-1297-1-ND | OSCILLATOR XO 50.000MHZ CMOS SMD
120 | 125MHz LVDS | 1 | XO6 | CRYSTAL_6-LCC | EPSON | SG3225VAN 125.000000M-KEGA3 | Digi-Key | SER3930CT-ND | 125MHz LVDS XO (Standard) Oscillator Surface Mount 2.5 V ~ 3.3 V 30mA Enable/Disable
121 | 25MHz | 1 | XT1 | CRYSTAL_4-LCC | ABRACON | ABM8-25.000MHZ-B2-T | Newark | 13J1767 | 25MHz ±20ppm Crystal 18pF 50 Ohm -20°C ~ 70°C Surface Mount 4-SMD, No Lead (DFN, LCC)
 |  |  |  |  |  |  |  |  |  | Total NF element number: 60
 |  |  |  |  |  |  |  |  |  | All NF elements in one row:
 |  |  |  |  |  |  |  |  |  | NF(C315 C316 C407 C334 C385 FR29 FR31 IC10 IC21 IC22 J17 LED1 LED4 MECH1 MECH2 MECH3 MECH4 MECH5 MECH6 MECH7 MECH8 MECH9 MECH10 MECH11 MECH12 MECH13 MECH14 MN6 MN22 MN34 MN50 MN14 MN42 R14 R17 R52 R55 R59 R60 R98 R99 R100 R109 R112 R114 R116 R117 R120 R122 R126 R133 R138 R179 R150 R164 VD1 VT6 VT7 XO1 XO3)
 |  |  |  |  |  |  |  |  |  | *NOTE: NF(R1 R2) means that elements R1 and R2 are unpopulated (NF)

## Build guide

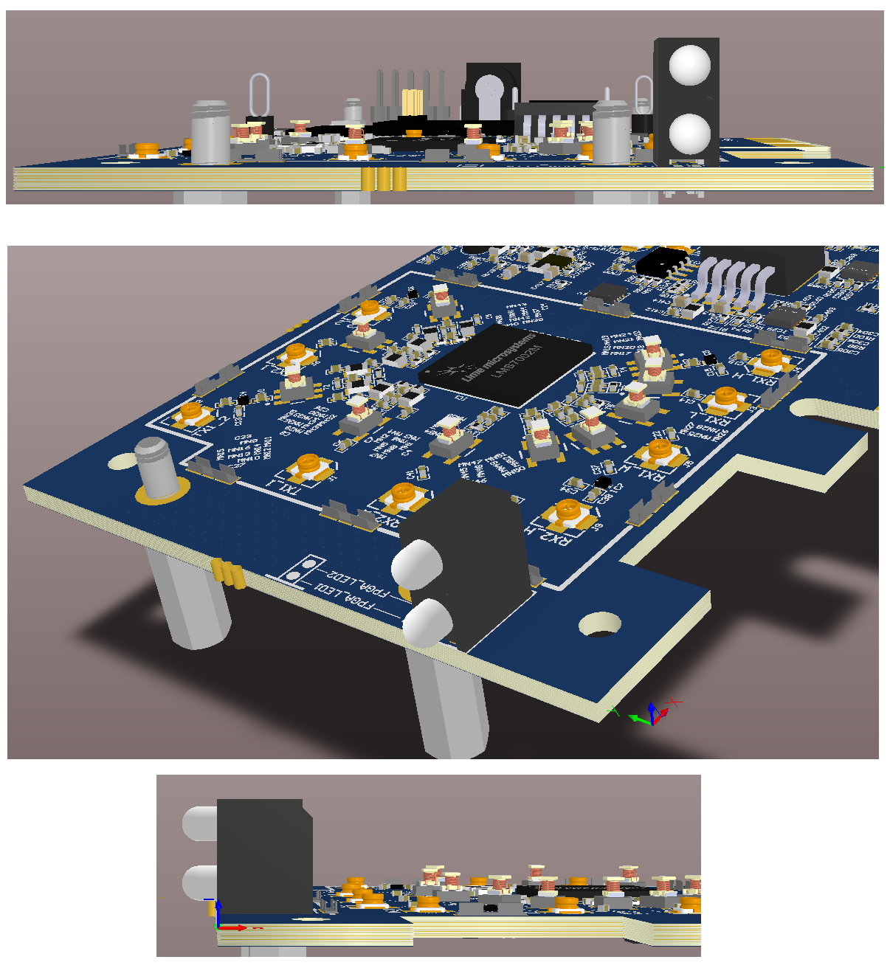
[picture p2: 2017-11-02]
hardware/1v3/EDA/Project Outputs for LimeSDR-PCIe_1v3/LimeSDR-PCIe_1v3_LEDS1_Assembled_View.png

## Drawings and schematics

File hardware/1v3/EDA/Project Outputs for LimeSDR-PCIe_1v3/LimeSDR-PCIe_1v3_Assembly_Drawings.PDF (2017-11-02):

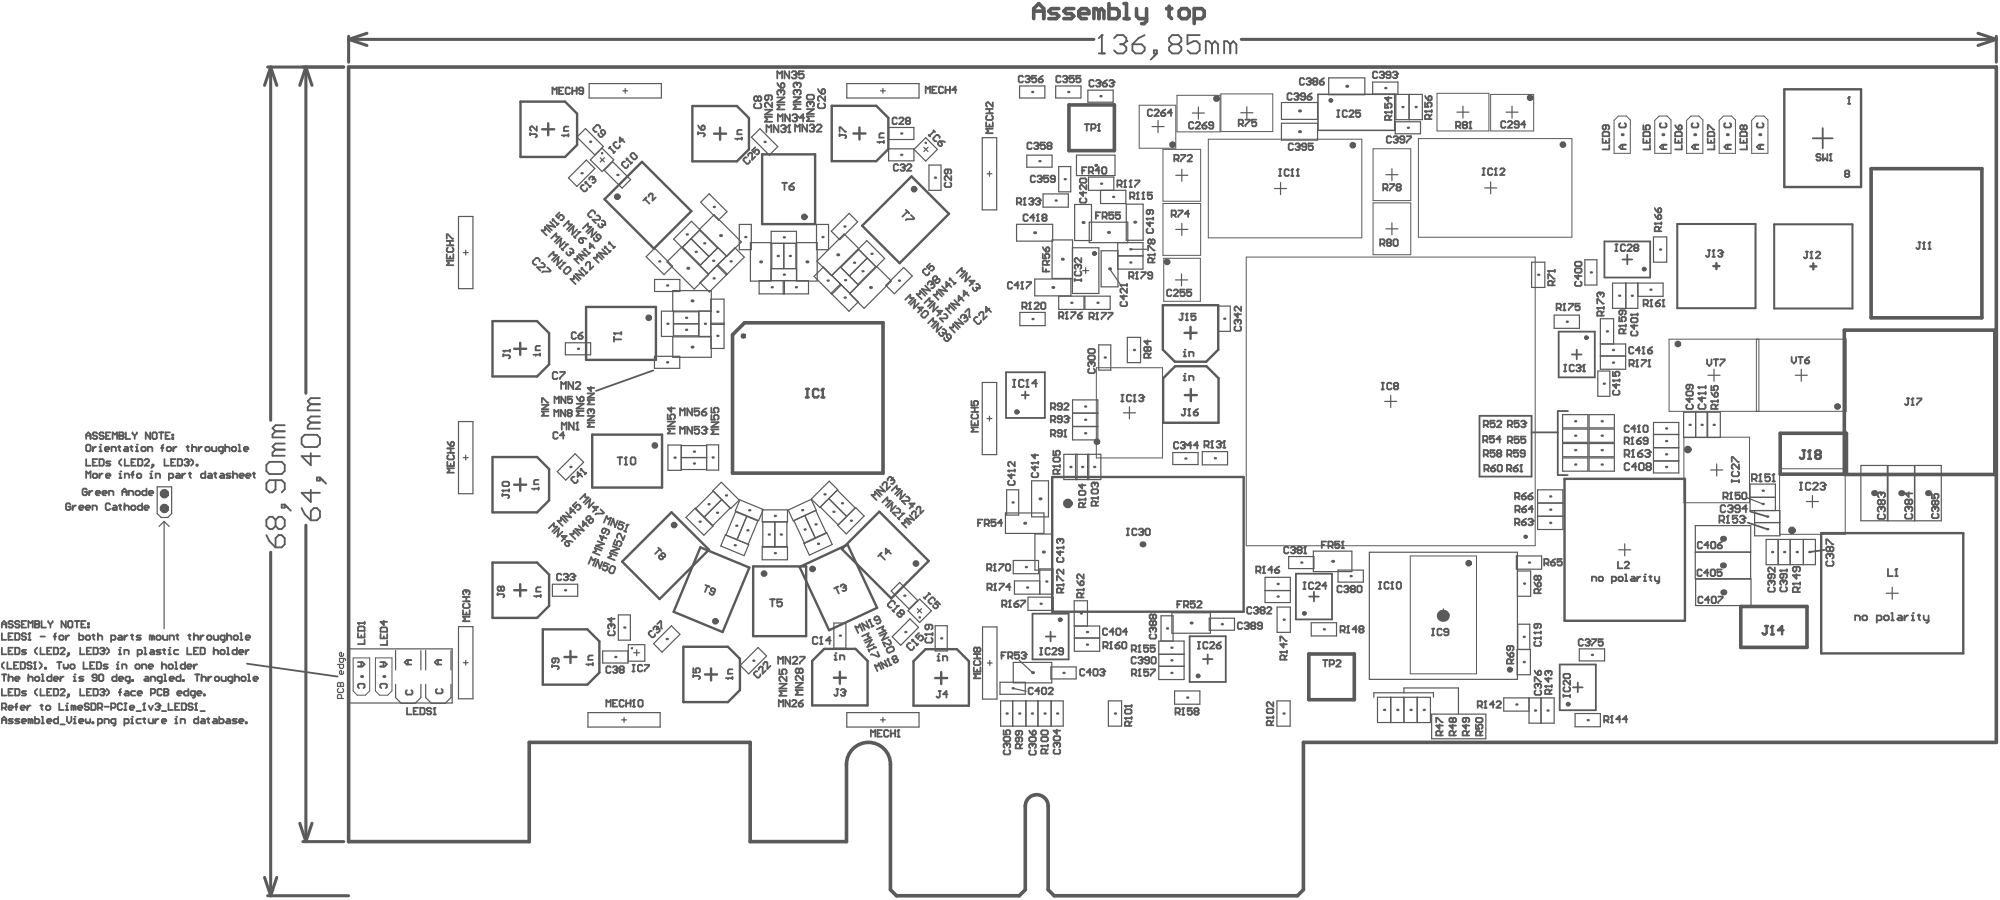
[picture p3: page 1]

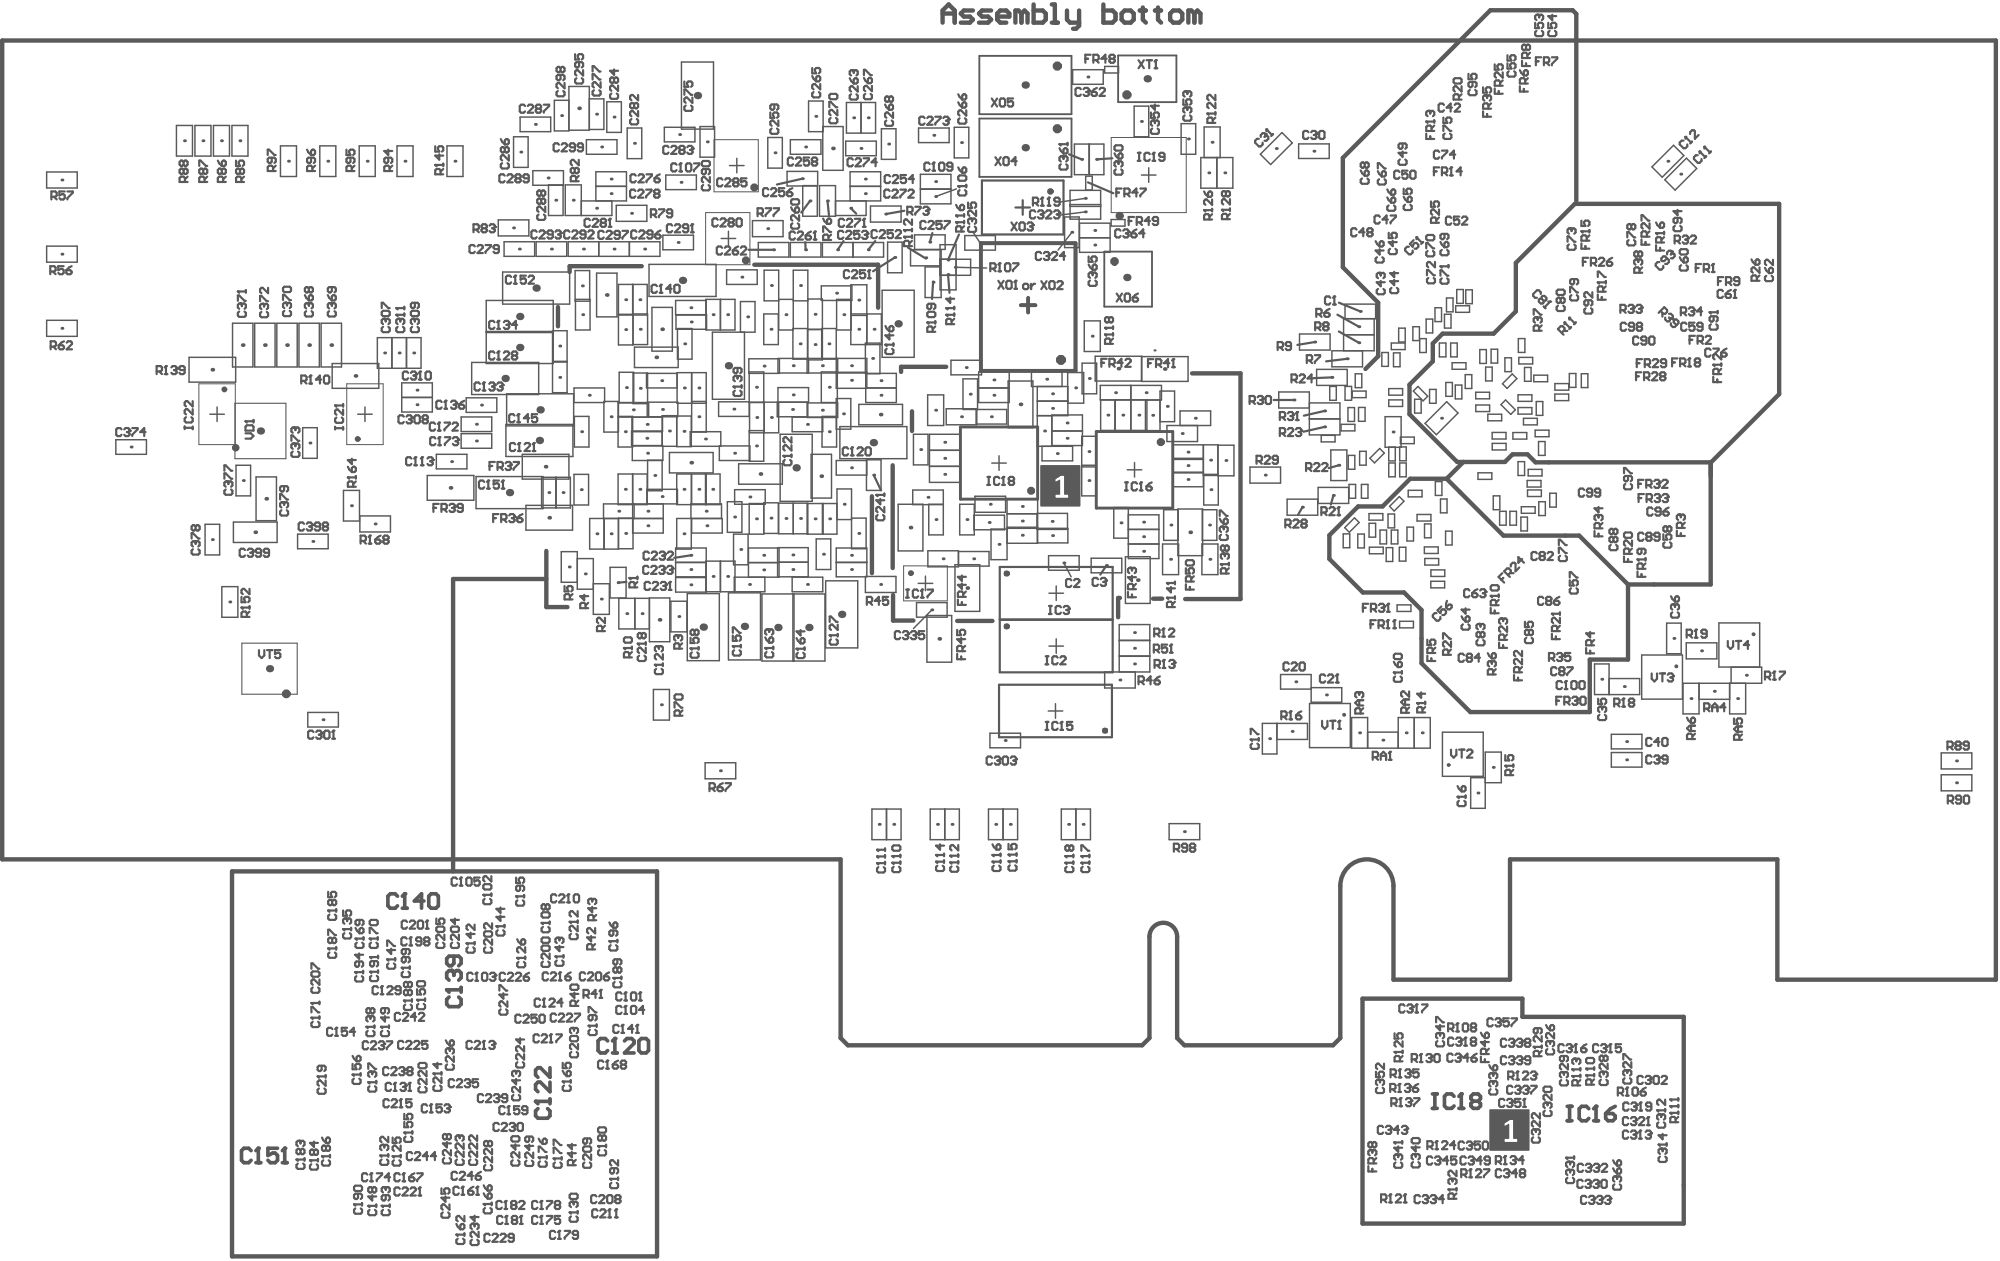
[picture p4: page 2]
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

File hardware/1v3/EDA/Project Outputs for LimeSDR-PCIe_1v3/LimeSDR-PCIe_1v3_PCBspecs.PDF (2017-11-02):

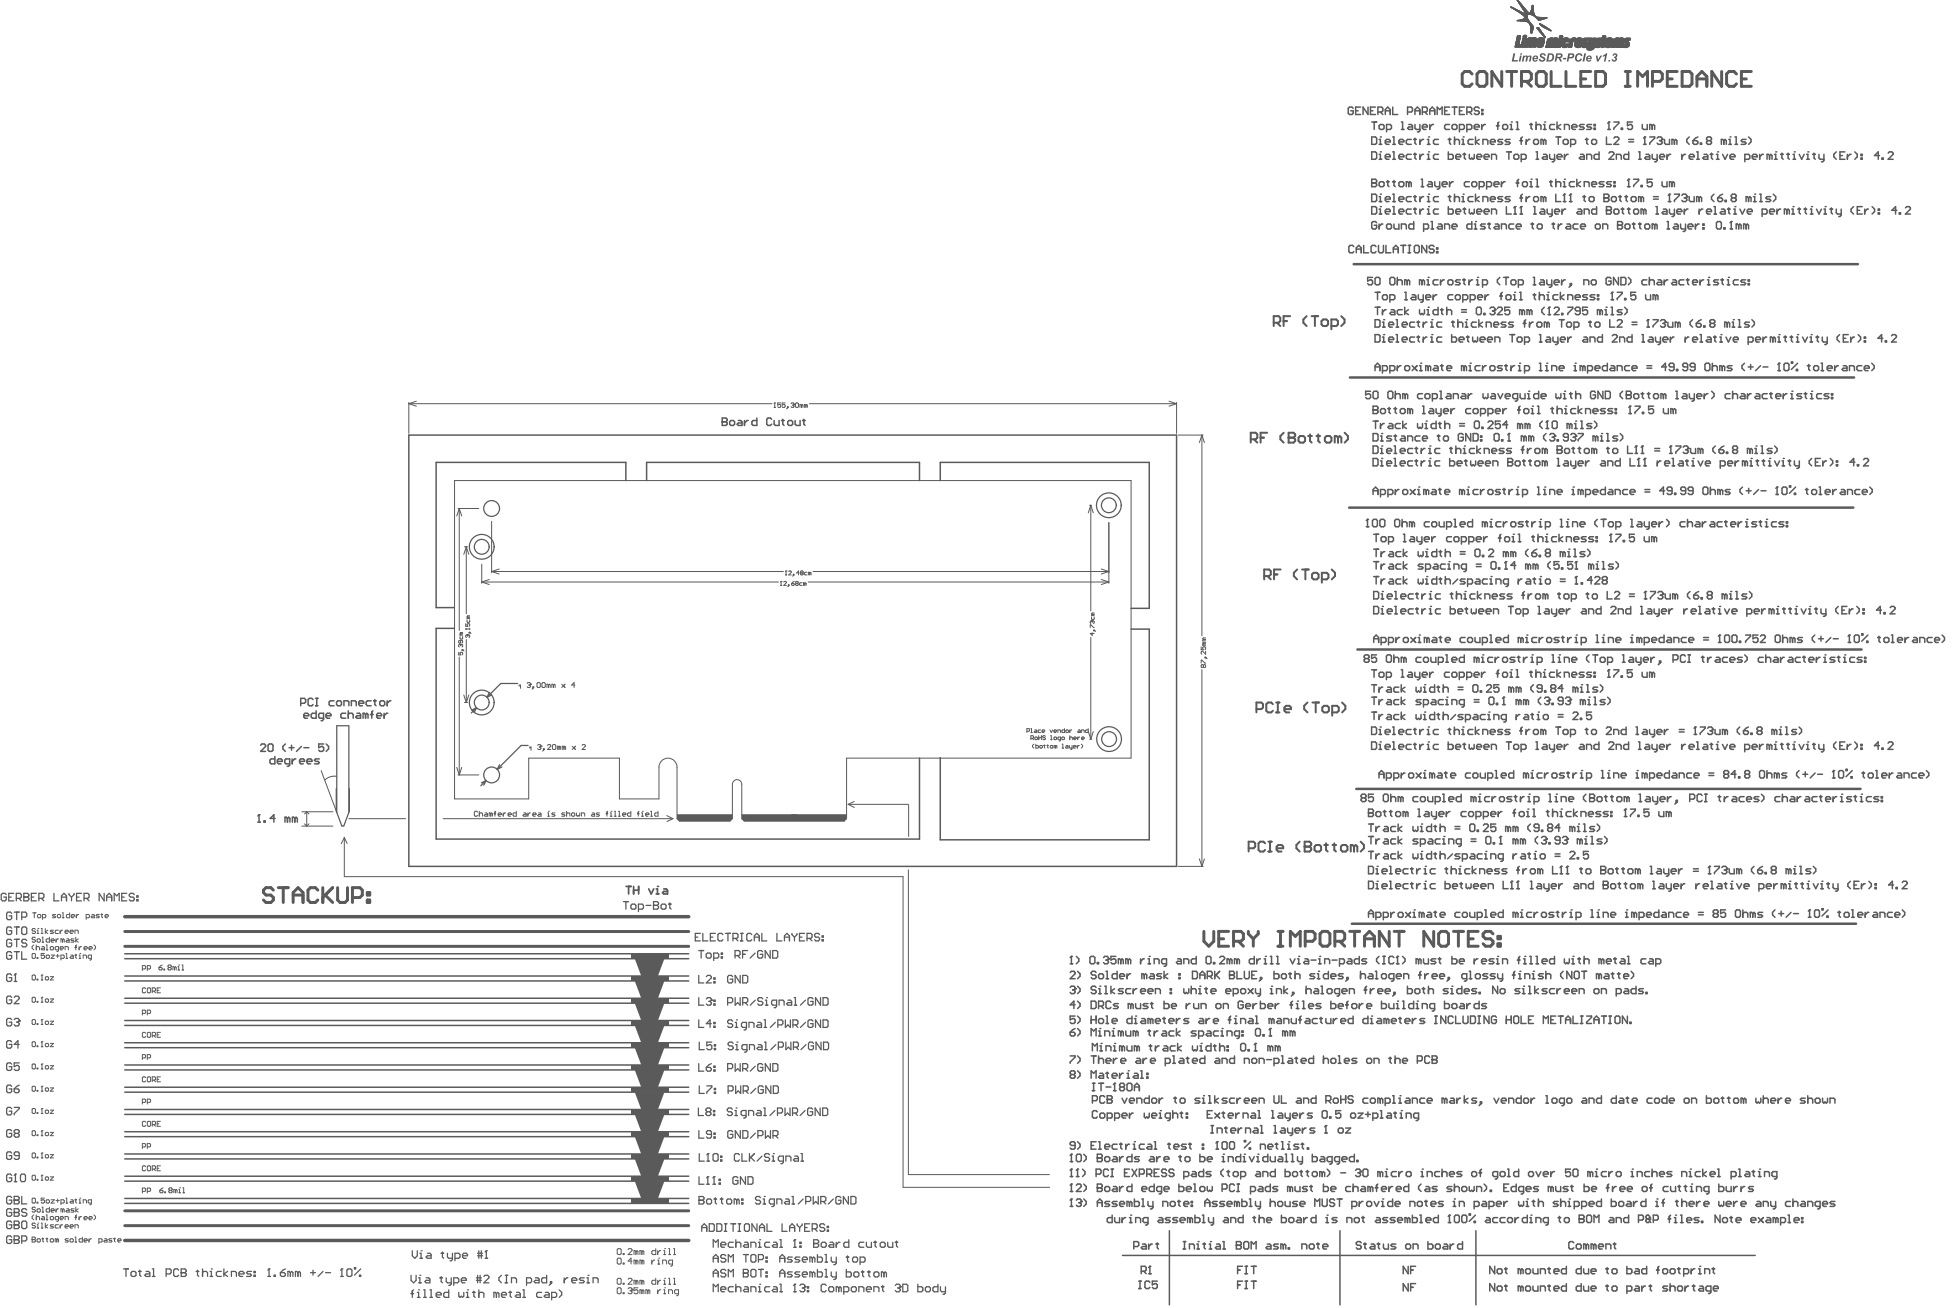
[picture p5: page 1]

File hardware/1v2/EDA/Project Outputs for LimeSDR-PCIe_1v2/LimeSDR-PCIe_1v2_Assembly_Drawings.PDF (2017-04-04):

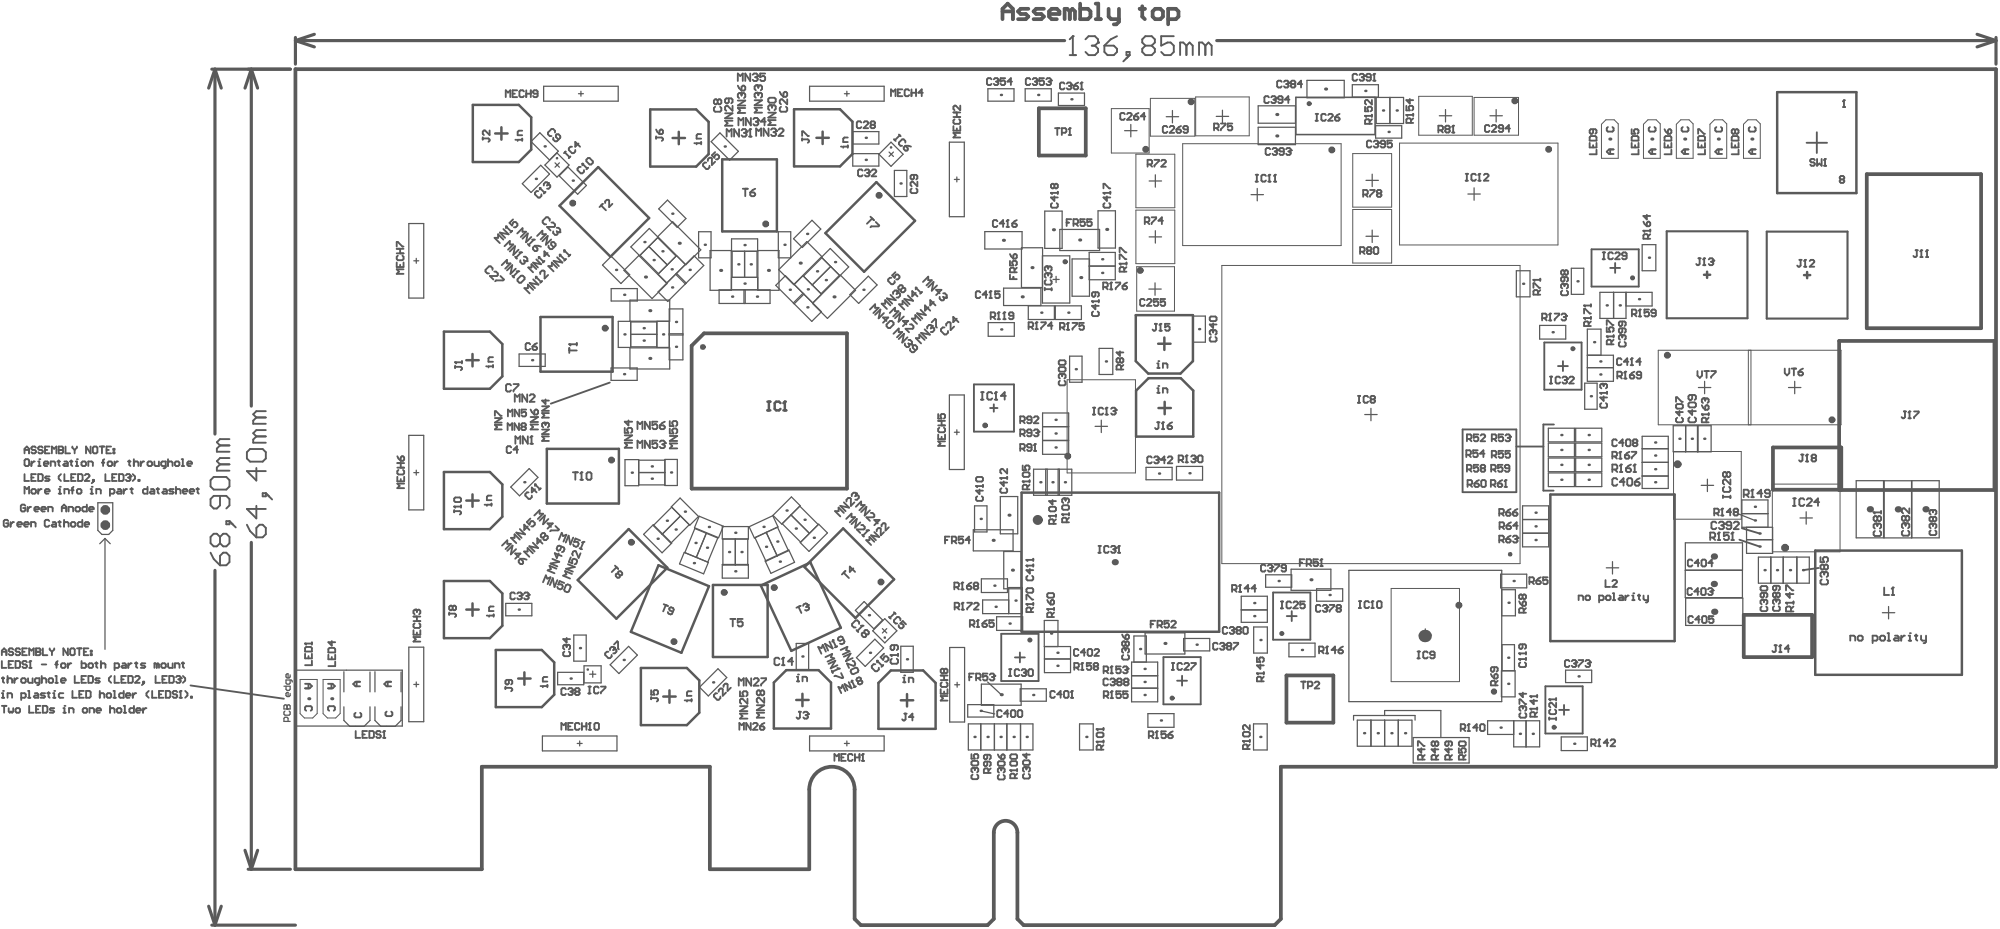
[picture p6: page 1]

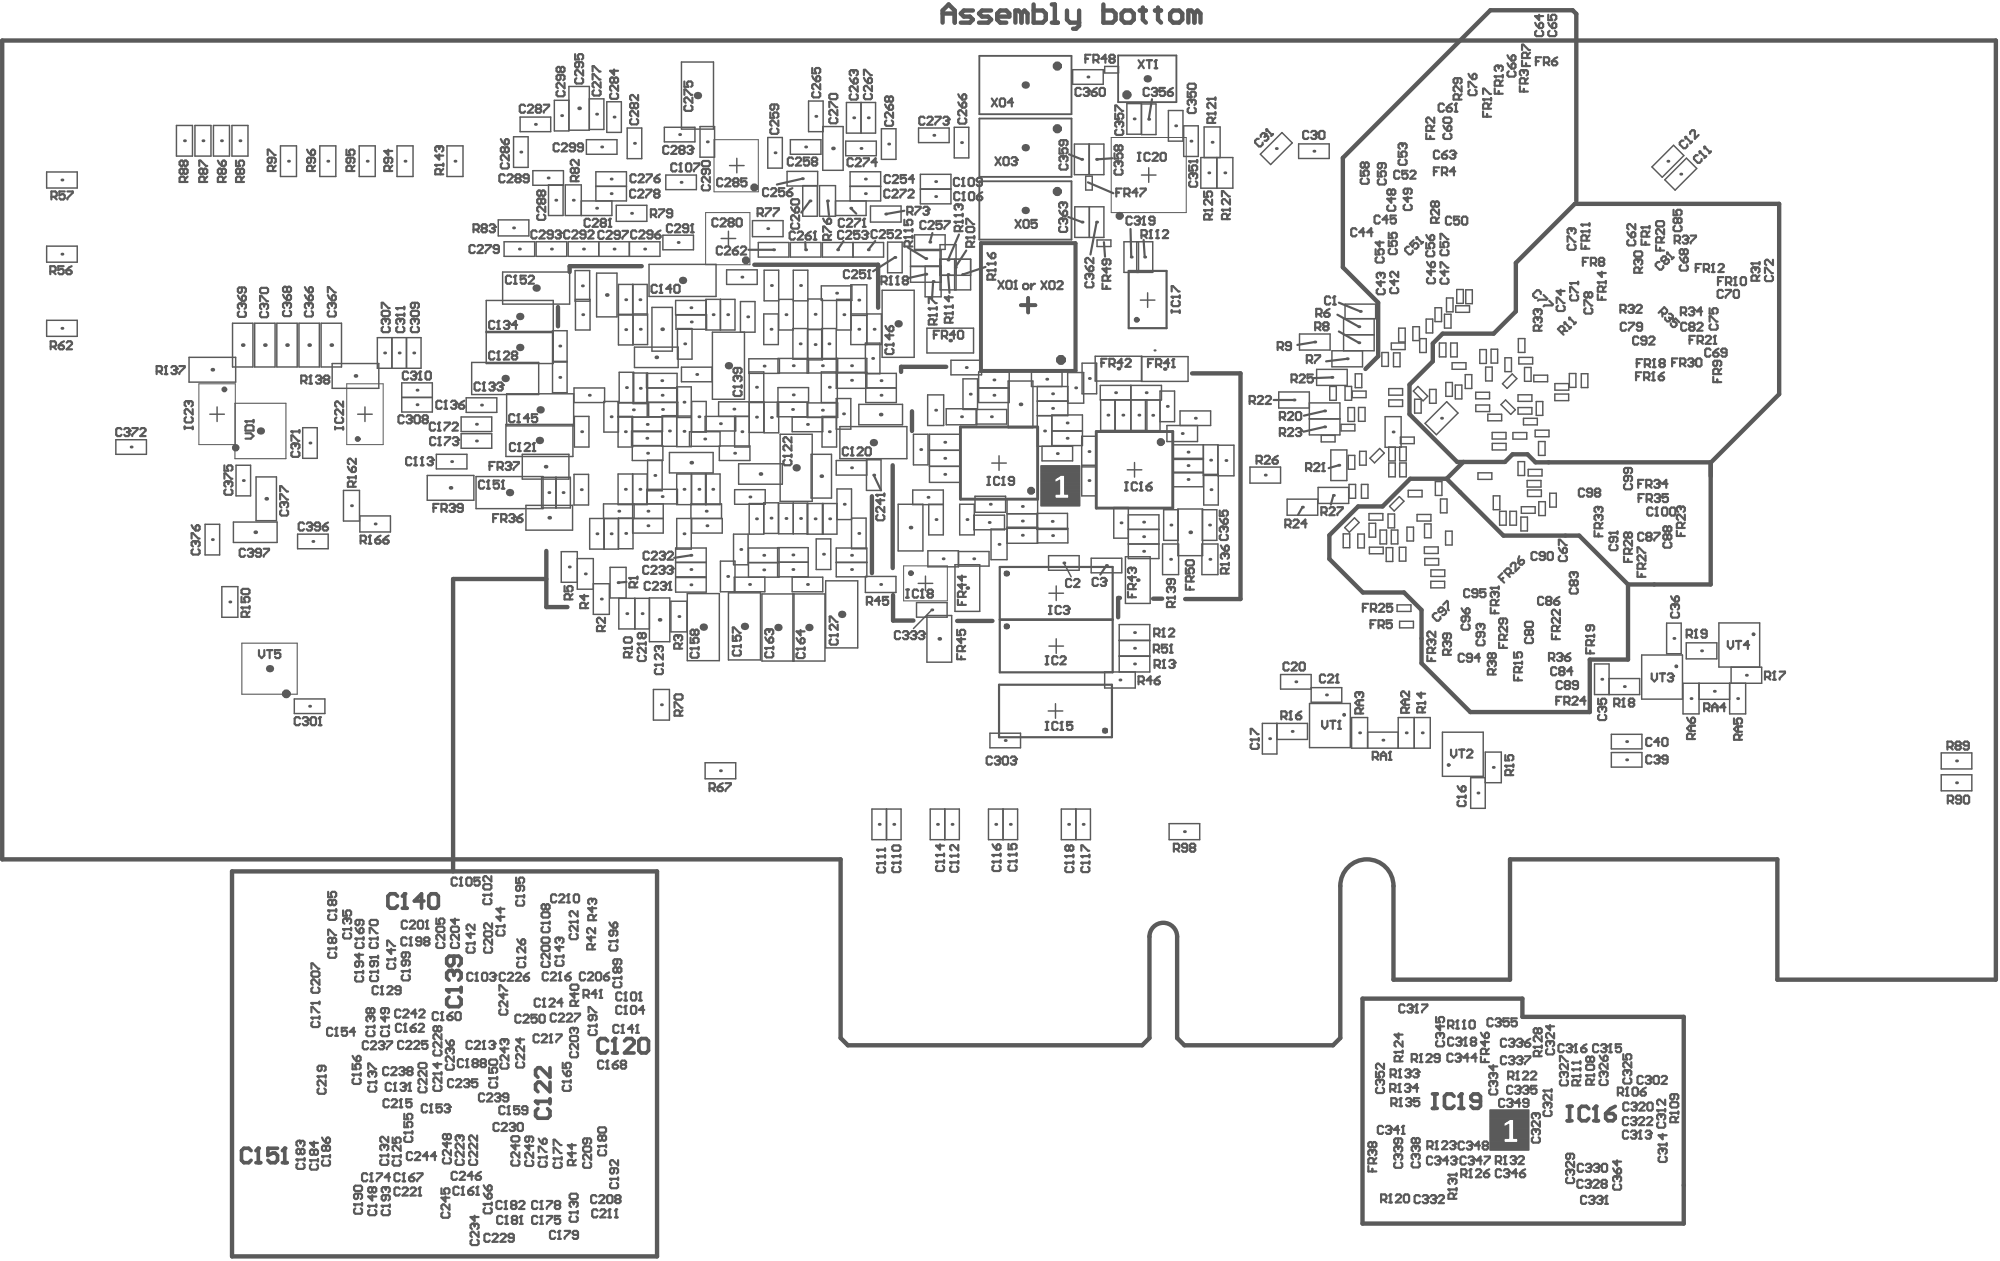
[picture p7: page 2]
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

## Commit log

2017-04-04 Altium project and DFM files for 1v2 board version added.
    [01_BlockDiagram.SchDoc, 02_PowerDiagram.SchDoc, 03_ClockDiagram.SchDoc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]
2017-04-04 DFM files of 1v0 moved to DFM folder.
    [SoDeRa-PCIe_1v0.GBL, SoDeRa-PCIe_1v0.GBO, SoDeRa-PCIe_1v0.GBP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]
2017-04-04 Folder structure of 1v0 changed.
    [01_BlockDiagram.SchDoc, 02_PowerDiagram.SchDoc, 03_ClockDiagram.SchDoc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]
2017-04-04 BOM file added to the Info folder for 1v0 board.
    [SoDeRa-PCIe_1v0_BOM.xls]
2017-11-02 1v3 PCB project added.
    [01_BlockDiagram.SchDoc, 02_PowerDiagram.SchDoc, 03_ClockDiagram.SchDoc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]
